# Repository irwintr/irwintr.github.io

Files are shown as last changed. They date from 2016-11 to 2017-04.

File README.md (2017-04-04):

---
csl: apa.csl
bibliography: RPiCitations.bib
---

**ActiveHouse**
===============

Project website <https://irwintr.github.io>

Prepared by Trenton Irwin

March 28, 2017

  \pagebreak   \linespread{2} \selectfont

**Declaration of Sole Authorship**
----------------------------------

I, Trenton Irwin, will be completing all of the work related to this project
including the hardware, database, web service, and mobile application. Any uses
made within it of the works of any other author, in any form (ideas, equations,
figures, texts, tables, programs), are properly acknowledged at the point of
use. A list of the references used is included. It is mandatory that all sources
of information be acknowledged in the SRS. Plagiarism is unethical and a
candidate suspected of plagiarizing may be referred to the Complaints Committee.

  \pagebreak

**Proposal**
------------

### **Proposal Table of Contents**

1.  [Proposal](https://github.com/irwintr/irwintr.github.io/blob/master/README.md#proposal)

2.  [Executive
    Summary](https://github.com/irwintr/irwintr.github.io/blob/master/README.md#executive-summary)

3.  [Background](https://github.com/irwintr/irwintr.github.io/blob/master/README.md#background)

4.  [Methodology](https://github.com/irwintr/irwintr.github.io/blob/master/README.md#methodology)

5.  [Concluding
    Remarks](https://github.com/irwintr/irwintr.github.io/blob/master/README.md#concluding-remarks)

6.  [References](https://github.com/irwintr/irwintr.github.io/blob/master/README.md#references)

The ActiveHouse Project would be a complete home monitoring system consisting of
multiple Arduino based sensor hubs in each room of your home wirelessly
connecting to a Raspberry Pi based base station which sends the data to the
server where it can be read by the app. Each sensor hub would be capable of
reading temperature, humidity, luminosity, carbon monoxide and other gas levels,
water consumption, power consumption, and it would have the ability to toggle
the built-in light. The power and water consumption sensors are detachable as
they would not necessarily be used in each room, thus creating a more modular
design. The app would allow users to view the current settings in each room and
over the complete house, toggle the lighting, and set a lighting schedule.

\#\#\# **Executive Summary**
----------------------------

As a Computer Engineering student, I’ll be using all of the skills I have
learned in the last 2 years in this program to complete this project. This
proposal requests the approval to build the hardware portion that will connect
to a database as well as to a mobile device application. The sensor hub hardware
will include a custom PCB with sensors and XBee wireless adapters and an Arduino
inside a custom printed box. The Base station hardware will include an XBee
wireless adapter connected to a Raspberry Pi. The database will store the sensor
data from each room. The mobile device functionality will allow users to view
the current settings in each room and over the complete house, toggle the
lighting, and set a lighting schedule. I may end up collaborating with the
greater Active House team later in the semester but I will not be working with
any companies. The hardware will be completed in CENG 317 Hardware Production
Techniques independently and the application will be completed in CENG 319
Software Project. These will be integrated together in the subsequent term in
CENG 355 Computer Systems Project.

\#\#\# **Background**
---------------------

The problem solved by this project is that it provides a home monitoring
solution so that users homes can be controlled and monitored remotely through an
intuitive app. It will help people monitor their resource consumption as well
which may help drive down consumption.

There are several other home monitoring solutions on the market now[@4429263],
but they are usually integrated into either the thermostat or home security
system. This is one of the first projects I’ve seen where water and power
consumption are also monitored on a residential scale.

In the Computer Engineering Technology program I have learned about the
following topics from the respective relevant courses:

-   Electronic Devices and Circuits – Soldering experience

-   Database with Java – Setting up database

-   Electronic Circuits – Voltage Divider calculations

-   Technical Workplace Writing – Creating write-ups and technical drawings

-   Software Engineering – Creating project schedules

This knowledge and skill set will enable me to build the subsystems and
integrate them together as my capstone project.

\#\#\# **Methodology**
----------------------

This proposal is assigned in the first week of class and is due at the beginning
of class in the second week of the fall semester. My coursework will focus on
the first two of the 3 phases of this project:  
Phase 1 Hardware build.  
Phase 2 System integration.  
Phase 3 Demonstration to future employers.

~~~~~~~~~~~~~~~~~~~~~~~~~~~~~~~~~~~~~~~~~~~~~~~~~~~~~~~~~~~~~~~~~~~~~~~~~~~~~~~~
*Phase 1 Hardware build*
~~~~~~~~~~~~~~~~~~~~~~~~~~~~~~~~~~~~~~~~~~~~~~~~~~~~~~~~~~~~~~~~~~~~~~~~~~~~~~~~

The hardware build will be completed in the fall term. It will fit within the
CENG Project maximum dimensions of 12 13/16" x 6" x 2 7/8" (32.5cm x 15.25cm x
7.25cm) which represents the space below the tray in the parts kit. The highest
AC voltage that will be used is 16Vrms from a wall adaptor from which +/- 15V or
as high as 45 VDC can be obtained. Maximum power consumption will be 20 Watts.

~~~~~~~~~~~~~~~~~~~~~~~~~~~~~~~~~~~~~~~~~~~~~~~~~~~~~~~~~~~~~~~~~~~~~~~~~~~~~~~~
*Phase 2 System integration*
~~~~~~~~~~~~~~~~~~~~~~~~~~~~~~~~~~~~~~~~~~~~~~~~~~~~~~~~~~~~~~~~~~~~~~~~~~~~~~~~

The system integration will be completed in the winter term.

*Phase 3 Demonstration to future employers*

This project will showcase the knowledge and skills that we have learned to
potential employers.

The tables below provide rough effort and non-labour estimates respectively for
each phase. A Gantt chart will be added by week 3 to provide more project
schedule details and a more complete budget will be added by week 4. It is
important to start tasks as soon as possible to be able to meet deadlines.

| **Labour Estimates** | **Hrs** | **Notes** |
|---|---|---|
| **Phase 1** | | |
| Writing proposal. | 9 | Tech identification quiz. |
| Creating project schedule. Initial project team meeting. | 9 | Proposal due. |
| Creating budget. Status Meeting. | 9 | Project Schedule due. |
| Acquiring components and writing progress report. | 9 | Budget due. |
| Mechanical assembly and writing progress report. Status Meeting. | 9 | Progress Report due (components acquired milestone). |
| PCB fabrication. | 9 | Progress Report due (Mechanical Assembly milestone). |
| Interface wiring, Placard design, Status Meeting. | 9 | PCB Due (power up milestone). |
| Preparing for demonstration. | 9 | Placard due. |
| Writing progress report and demonstrating project. | 9 | Progress Report due (Demonstrations at Open House Saturday, November 7, 2015 from 10 a.m. - 2 p.m.). |
| Editing build video. | 9 | Peer grading of demonstrations due. |
| Incorporation of feedback from demonstration and writing progress report. Status Meeting. | 9 | 30 second build video due. |
| Practice presentations | 9 | Progress Report due. |
| 1st round of Presentations, Collaborators present. | 9 | Presentation PowerPoint file due. |
| 2nd round of Presentations | 9 | Build instructions up due. |
| Project videos, Status Meeting. | 9 | 30 second script due. |
| **Phase 1 Total** | **135** | |
| **Phase 2** | | |
| Meet with collaborators | 9 | Status Meeting |
| Initial integration. | 9 | Progress Report |
| Meet with collaborators | 9 | Status Meeting |
| Testing. | 9 | Progress Report |
| Meet with collaborators | 9 | Status Meeting |
| Meet with collaborators | 9 | Status Meeting |
| Incorporation of feedback. | 9 | Progress Report |
| Meet with collaborators | 9 | Status Meeting |
| Testing. | 9 | Progress Report |
| Meet with collaborators | 9 | Status Meeting |
| Prepare for demonstration. | 9 | Progress Report |
| Complete presentation. | 9 | Demonstration at Open House Saturday, April 9, 2016 10 a.m. to 2 p.m. |
| Complete final report. 1st round of Presentations. | 9 | Presentation PowerPoint file due. |
| Write video script. 2nd round of Presentations, delivery of project. | 9 | Final written report including final budget and record of expenditures, covering both this semester and the previous semester. |
| Project videos. | 9 | Video script due |
| **Phase 2 Total** | **135** | |
| **Phase 3** | | |
| Interviews | TBD | |
| **Phase 3 Total** | **TBD** | |
| **Material Estimates** | **Cost** | **Supplier** |
| **Phase 1** | | |
| Cannakit Raspberry Pi v3 | \$99.99 | Amazon.ca |
| Arduino Uno SMD Rev3 | \$31.08 | Digi-key |
| Xbee S1 Trace Antenna (x2) | \$53.68 | Digi-key |
| Xbee Shield for Arduino | \$22.77 | Digi-key |
| 3.5mm audio jack | \$2.09 | Canada Robotix |
| Non-Invasive Current Sensor | \$13.19 | Canada Robotix |
| Adafruit Gas Sensor | \$21.12 | Digi-key |
| Adafruit Light Sensor | \$8.40 | Digi-key |
| Water Flow Sensor | \$11.89 | Canada Robotix |
| 3 Pin Molex header | \$0.39 | Canada Robotix |
| 12mm Buzzer | \$1.99 | Canada Robotix |
| Adafruit Temperature and Humidity Sensor | \$19.70 | Digi-key |
| *Shipping* | *\$6.95* | |
| *Tax* | *\$37.22* | |
| **Phase 1 Total** | **\$330.46** | |
| **Phase 2** | | |
| Materials to improve functionality, fit, and finish of project. | N/A | |
| **Phase 2 Total** | **TBD** | |
| **Phase 3** | | |
| **Phase 3 Total** | **TBD** | |

\#\#\# **Concluding remarks**
-----------------------------

This proposal presents a plan for providing an IoT solution for a home
monitoring system. This is an opportunity to integrate the knowledge and skills
developed in the Computer Engineering program to create a collaborative IoT
capstone project demonstrating my ability to learn how to support projects. I
request approval of this project.

  \pagebreak

**Abstract**
------------

This report contains information outlining the ActiveHouse home monitoring
system project. The project aims to create a complete home enviromental
monitoring system to measure temperature, humidity, light levels, water
consumption, power consumption, smoke and gas detection, and the ability to
toggle lights. There is an Android mobile application for displaying the data
and making changes. The hardware consists of a Raspberry Pi, an Arduino, xBee
wireless adapters, and a mirriad of sensors. The web service and database to
store all the data is hosted on Munro.humber.ca. The total cost for the
prototype is about \$330. The project will take me about 8 months to complete
but can be redone in much less time.  

  \pagebreak

**Table of Contents**
---------------------

1.  [Declaration of Sole
    Authorship](https://github.com/irwintr/irwintr.github.io/blob/master/README.md#declaration-of-sole-authorship)

2.  [Proposal](https://github.com/irwintr/irwintr.github.io/blob/master/README.md#proposal)

3.  [Abstract](https://github.com/irwintr/irwintr.github.io/blob/master/README.md#abstract)

4.  [Table of
    Contents](https://github.com/irwintr/irwintr.github.io/blob/master/README.md#table-of-contents)

5.  [List of Illustrations or
    Diagrams](https://github.com/irwintr/irwintr.github.io/blob/master/README.md#list-of-illustrations-or-diagrams)

6.  [Introduction](https://github.com/irwintr/irwintr.github.io/blob/master/README.md#introduction)

7.  [Project
    Description](https://github.com/irwintr/irwintr.github.io/blob/master/README.md#project-description)

8.  [Conclusion](https://github.com/irwintr/irwintr.github.io/blob/master/README.md#conclusion)

9.  [Appendicies](https://github.com/irwintr/irwintr.github.io/blob/master/README.md#appendicies)

10. [Bibliography](https://github.com/irwintr/irwintr.github.io/blob/master/README.md#bibliography)

  \pagebreak

**List of Illustrations or Diagrams**
-------------------------------------

1.  Project Workflow diagram

2.  Budget / Parts list

3.  XBee breakout board

4.  XBee to Pi wiring diagram

5.  Sensor Hub

6.  Sensor Hub

7.  Sensor Hub

8.  Sensor Hub

9.  Raspberry Pi base station

10. Sensor Hub

11. Sensor Hub

12. Sample output from sensor hub

13. Sensor hub with sensors attached

\pagebreak

**Introduction**
----------------

The ActiveHouse Project is a complete home monitoring system consisting of
multiple Arduino based sensor hubs in each room of your home wirelessly
connecting to a Raspberry Pi based base station which sends the data to the
server where it can be read by the app. Each sensor hub is be capable of reading
temperature, humidity, luminosity, carbon monoxide and other gas levels, water
consumption, power consumption, and it would have the ability to toggle the
built-in light. The power and water consumption sensors are detachable as they
would not necessarily be used in each room, thus creating a more modular design.
The app allows users to view the current settings in each room and over the
complete house, toggle the lighting, and set a lighting schedule.

  \pagebreak

**Project Description**
-----------------------

The ActiveHouse project consists of two main pieces of hardware:

Raspberry Pi based base station with an Xbee wireless antenna connected to it.

Arduino based sensor hub which includes the following:

–Xbee Wireless Antenna

–Light Sensor

–Gas Sensor

–Current Sensor

–Water Flow Sensor

–Temperature Sensor

–Humidity Sensor

–Remote Controllable Light

–Buzzer

You can have as may sensor hubs as you want hooked up to one base station, they
jut need to be within the 300 foot range for the XBees.

There are 5 main software components at work in the Active House system; the
Arduino code running on the Sensor Hubs, the C++ code running on the Raspberry
Pi base station, the PHP Web Service Running on Munro, the MySQL database on
Munro, and the mobile Android app.

### **Sensor Hub Code**

**Arduino Specifications**

The Arduino program communicates with the Base station over the XBee serial
communication to send sensor data and toggle the light status.

**Code Breakdown**

The program is written to initialize all of the sensors. After that, it waits
and listens on the XBee serial port for communication from the base station.
When it receives a message from the base station that includes that sensor hub’s
unique ID, it replies with all of the sensor data.

### **Base Station Code**

**Raspberry Pi Specifications**

The Raspberry Pi based Base Station is used to communicate with the Sensor Hubs
over the XBee serial communication to gather all of the sensor data and send it
to the web service running on Munro.

\*\* Code Breakdown\*\*

The code that is running on the Raspberry Pi is written in C++ using the
ArduPi.cpp library which makes it easier to communicate using the Xbee. The
service has a list of the registered sensor hubs, and goes in order,
broadcasting each RoomID over the Xbee. When the corresponding sensor hub
receives this message, it will reply with all of its sensor data. The Base
Station code then parses that response and sends it back to the web service that
is running on Munro.

### Database Specifications

**Database Type**

For the ActiveHouse project I am using a MySQL database hosted on Munro. It can
be administered through phpMyAdmin.

**Database Tables**

There are four tables that are used in the Firebase.

1.  USERS

2.  HOUSE

3.  ROOM

4.  ROOM\_DATA

**USERS** is the table in which all users who sign up for the ActiveHouse
application are stored. They are given a key as a unique identifier.

**HOUSE** is the table in which the names of houses and their data are stored.
Each house is unique via an HOUSEID identification key within the table.

**ROOM** is the table in which the rooms in each house are stored. It contains
the HOUSEID that it corresponds with, a unique ROOMID and the room name.

**ROOM\_DATA** is the table where the sensor readings for each room are stored.
It is identified by the unique ROOMID.

**Work Breakdown**

There is no further work that needs to be done to the database.

### **Mobile Application Specifications**

**Graphical User Interface Specifications**

**MainActivity:** The login screen of the application is the first presented
upon launching the application. The user may enter already existing credentials
into EditText fields and login, or may choose to go to the sign up activity,
both navigations via Buttons. There is a checkbox to save the entered username
to local storage to be auto populated in future sessions.

**RegisterActivity:** The sign up screen of the application can be accessed from
the login screen. It has EditText fields for gathering new user information
including their HOUSEID. Without a HOUSEID, they cannot create a new account.
Incorrect EditText entries will be communicated via Toast message asking for
re-entry.

**HomeActivity:** This is the main screen of the app where the user can view the
current settings of the user’s house. There is a hamburger menu with links to
the other pages including one for each room in the home. Users can logout from
the menu bar.

**RoomActivity:** This page has the sensor data from an individual room
displayed. The user can interact with the page by toggling the light or light
schedule or setting the time on or off for the light. There is a hamburger menu
with links to the other pages including one for each room in the home. Users can
logout from the menu bar.

**RoomViewActivity:** The room view activity is a listview with all of the rooms
in it. Users can select the room they wish to view and be taken to the
RoomActivity page for that room.

**Application Work Breakdown**

There are a few small bugs that I need to patch, but the app is working and
pretty much complete.

### **Web Specifications**

**Web Service Specifications**

The web service is written in php and hosted on Munro. It can be accessed at
munro.humber.ca/\~n01046059/ActiveHouse.

**Web Work Breakdown**

The side of the web service that interacts with the mobile app is complete and
does not require any changes. I do need to write the side of the web service
that connects to the Raspberry Pi to send and receive sensor data. Additionally
I need to write a program to run on the Raspberry Pi to send the data to the
server.

\pagebreak

### **Build Instructions**

My Active House project is a complete home monitoring system. The idea is that
you would have one Sensor Hub in each room of your home to collect data You
would have one Raspberry Pi based base station which all of the sensor hubs send
their data wirelessly to. The base station then sends the received sensor data
to the database for use in my app.



#### Parts:

Here is a list of all the parts and aproximate costs for one Raspberry Pi base
station and one Sensor Hub:

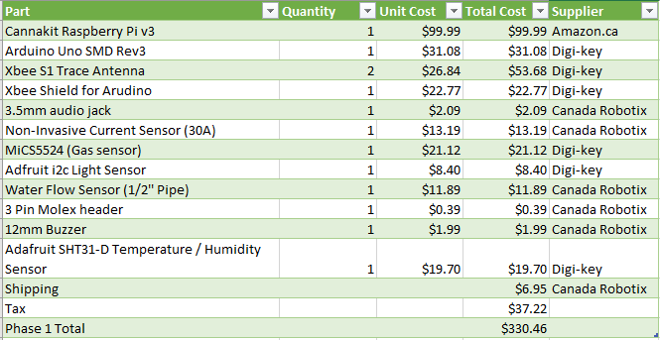
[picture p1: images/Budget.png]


This list does not include parts from the Humber electronics parts kit. The
parts you will need from the kit are:

-   220ohm Resistor

-   33ohm Resistor

-   2x 10Kohm Resistors

-   LED

-   50uf Capacitor

-   Single Core Wire

You will also need to print out the Acrylic case which can be found
[here](https://github.com/irwintr/irwintr.github.io/tree/master/Case) and the 2
PCBs which can be found
[here](https://github.com/irwintr/irwintr.github.io/tree/master/ArdunioShield)
and
[here](https://github.com/irwintr/irwintr.github.io/tree/master/XBeeBreakout).

#### Time Commitment

While it took me probably upwards of 30 hours to design the project and the
circuit boards, put it all together, and code it, I'd expect it to only take
around 5 hours to build the project again.

#### PCB/Soldering



The first board you will need to solder is the XBee Breakout board. You only
need to solder the 3.3v, GND, RX and TX pins as seen in this diagram:

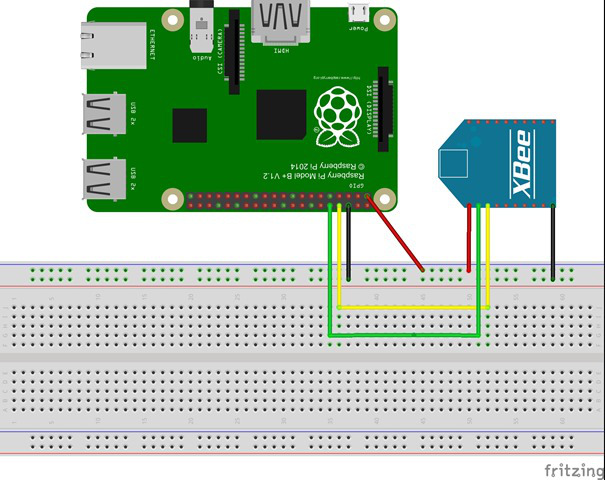
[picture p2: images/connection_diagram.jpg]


Then you will need to solder the Arduino Shield which includes all of the
sensors and connections. You can view the board and schematic files for this
board
[here](https://github.com/irwintr/irwintr.github.io/tree/master/ArdunioShield)
which will explain where all of the components and connections go. Beware, some
of the solder pads on the Arduin Shield are very small and you will need a very
steady hand to solder them. Below are a collection of images which will help you
understand where everything goes and how it is connected:









#### Mechanical Assembly



First, you will need to unbox your Raspberry Pi and set it up. You can view my
unboxing video [here](#Section_2). After that, connect the wires from the Xbee
breakout board to the appropriate GPIO pins.



Next you will need to build your acrylic case for your Arduino. Glue the all but
the back side together and glue the ports for the current and liquid sensors
onto the rear panel of the case.



#### Code

You can view the Arduino Code
[here](https://github.com/irwintr/irwintr.github.io/tree/master/ArduinoCode) to
read all of the sensor data and output it to Serial. You will also need to
include the Libraries folder. Due to a limitation with the Arduino Uno and the
Arduino XBee Shield, you cannot upload code to the Arduino while the XBee shield
is plugged in, so it needs to be removed from the arduino board when uploading.
Alternativly, you could flash the Arduino Uno's bootloader with the Duemilanove
which supports uploading code over XBee and send the code to the Arduino
wirelessly from the Raspberry Pi. You can read about how to flash the bootloader
[here](https://learn.sparkfun.com/tutorials/installing-an-arduino-bootloader)

#### Power Up

The output from the Arduino is below. You can also view my power up in my Build
Video.

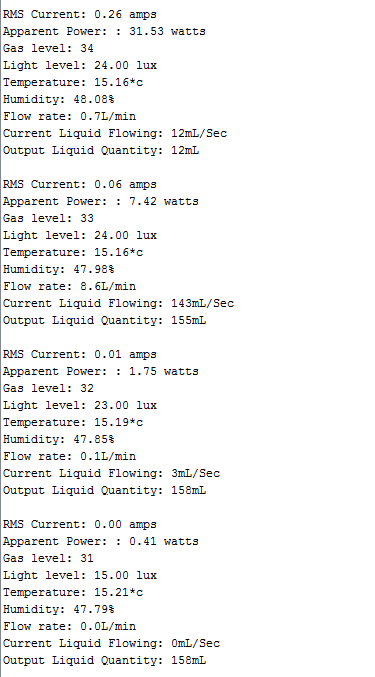
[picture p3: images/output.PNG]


#### Testing

In all of the testing I have done so far, everything works as expected. I've
checked the read values from the temperature, humidity, light, and gas sensors
and they all seem to be accurate. I have noth been able to find a 1/2" hose to
connect to my liquid flow sensor so I've been unable to calibrate it, but
tripping it by blowing air trough it works as expected. I've tested the current
sensor with a few different appliances and its's read values seem to be close to
the expected range, howeer I still need to completely calibrate it with an
clampmeter. The buzzer and LED can both be toggled from within the code.



\pagebreak

**Conclusions**
---------------

 The ActiveHouse project is nearly complete and will be within the next week. It
was definately a learning experience, but I fell like it was a sucessful
project. There are a few things I might do differently next time including
adding a Sync button to both the base station and the sensor boxes to pair them
automatically, however my current method of pairing works just fine. All of the
components of the project are working flawlessly together as expected, there is
just a bit of coding left to be done. The ActiveHouse project has great
potential as a home monitoring system as it has many features included such as
water and power consumption monitoring that aren't included in commercial
solutions that are currently on the market. Unfortunately, the fact that it's
build using mainly consumer hardware such as the Raspberry Pi and the Arduino
makes it not financially viable to birng to market without compltetely
rebuilding it all using cheaper microcontrollers. It was still a very good
learning experience and the skills that I have learned on this project will keep
me tinkering with electronics for years to come.  

\pagebreak

**Appendicies**
---------------

  \pagebreak

**Bibliography**
----------------

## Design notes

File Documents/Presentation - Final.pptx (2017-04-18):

## Active House

Trenton Irwin

## Introduction

- My Active House project is a complete home monitoring system.
- The idea is that you would have one Sensor Hub in each room of your home to collect data.
- You would have one Raspberry Pi based base station which all of the sensor hubs send their data wirelessly to via the Xbee wireless modules I have installed in all devices.
- The base station then sends the received sensor data to the web service which adds to to the database for use in my app.

- Raspberry Pi based base station with an Xbee wireless antenna connected to it.
- Arduino based sensor hub which includes the following:
  - Xbee Wireless Antenna
  - Light Sensor
  - Gas Sensor
  - Current Sensor
  - Water Flow Sensor
  - Temperature Sensor
  - Humidity Sensor
  - Remote Controllable Light
  - Buzzer

## Budget

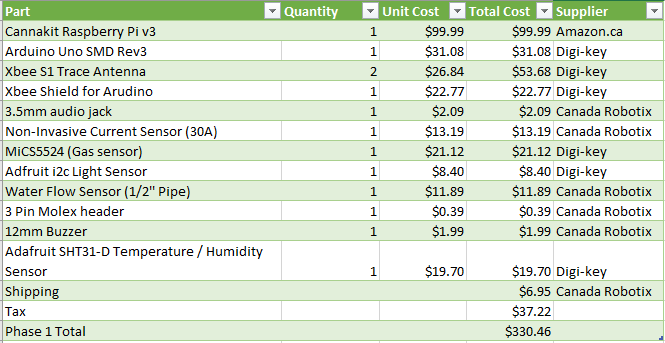
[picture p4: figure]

## Project Schedule

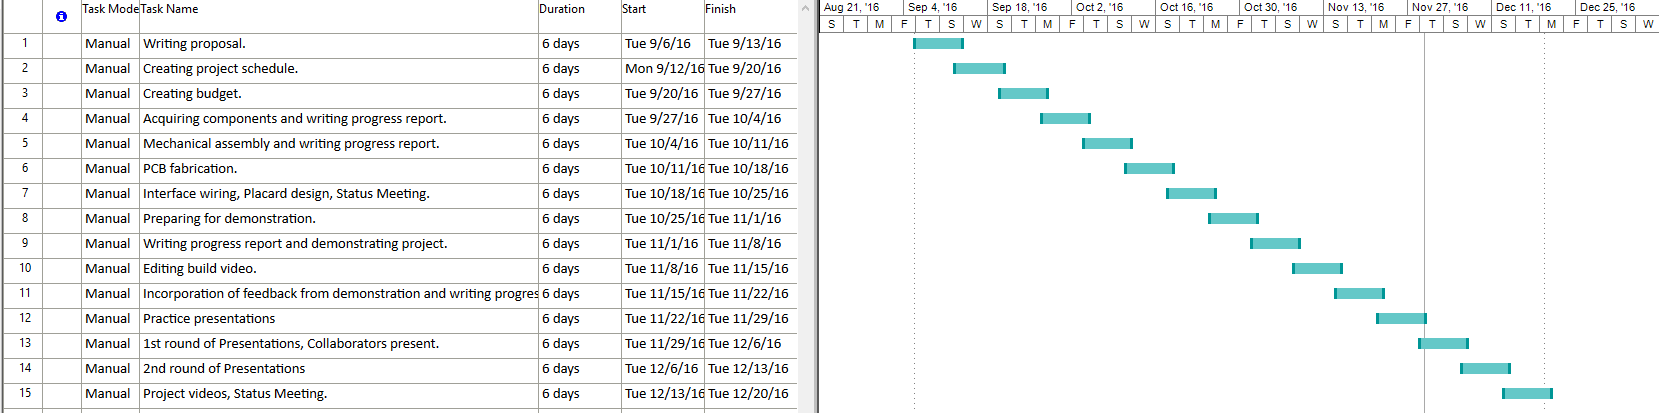
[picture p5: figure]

## Knowledge Used From Other Classes

- Electronic Devices and Circuits – Soldering experience
- Database with Java – Setting up database
- Electronic Circuits – Voltage Divider calculations
- Technical Workplace Writing – Creating write-ups and technical drawings
- Software Engineering – Creating project schedules
- Internet Programming – Writing web service

## Hardware

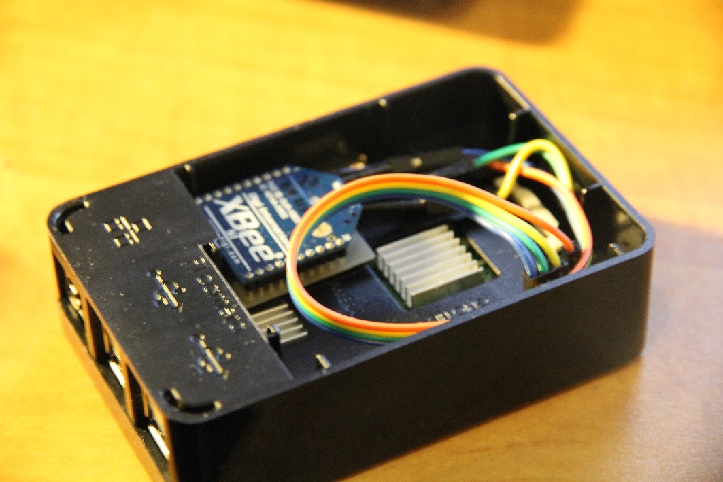
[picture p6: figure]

- Base Station
- Raspberry Pi 3 with Xbee Wireless module

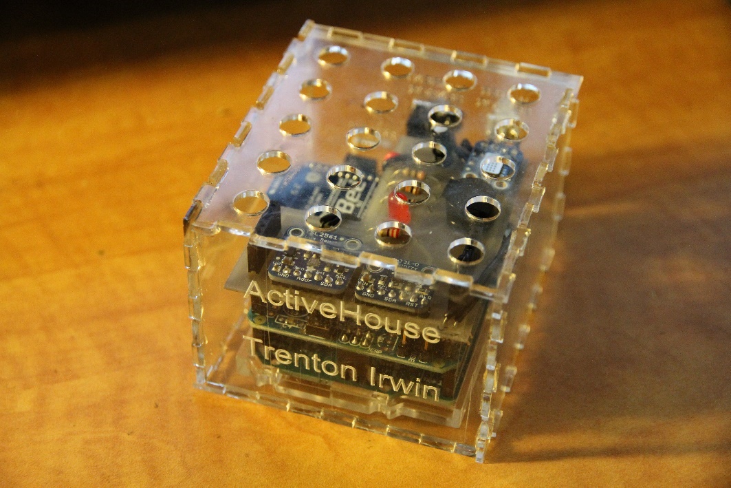
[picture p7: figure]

- Sensor Hub
- Arduino Uno with Xbee Wireless Antenna, Light Sensor, Gas Sensor, Current Sensor, Water Flow Sensor, Temperature Sensor, Humidity Sensor, Remote Controllable Light, and Buzzer

## Mobile Android Application

- The ActiveHouse Android app is used to view all of the sensor data from the

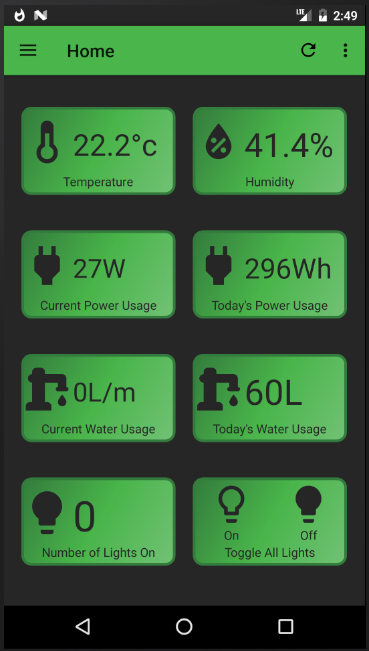
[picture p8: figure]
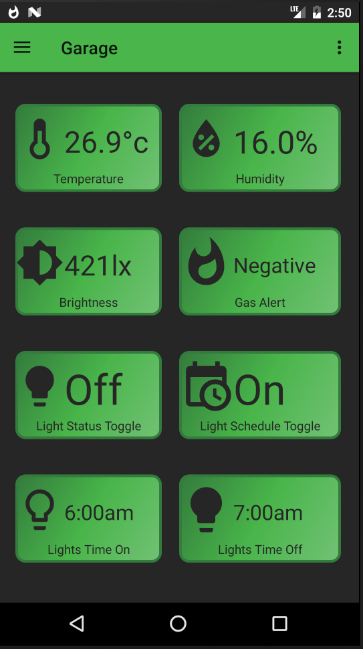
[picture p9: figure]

## Web Interface / Database

- I am using a MySQL database hosted on Munro to store all of my sensor data
- The web service is written in PHP and is used to communicate with both the mobile app and the Raspberry Pi base stations to send and receive data from the database.

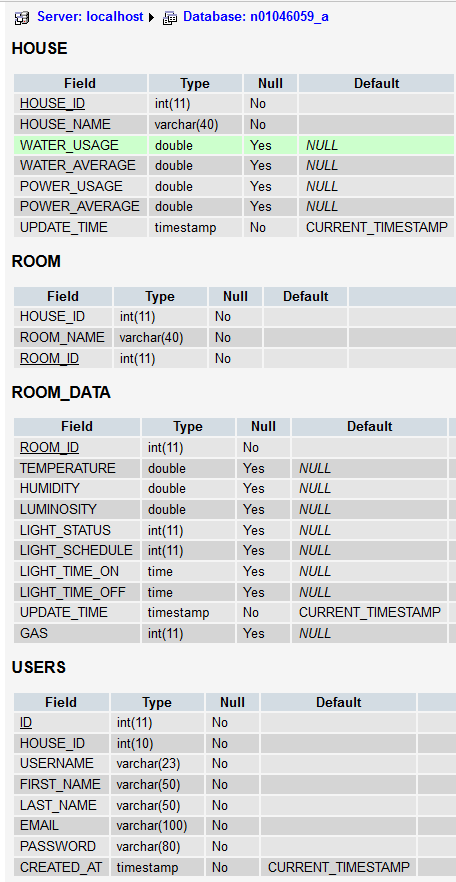
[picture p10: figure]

## Conclusion

- I consider my project to be a success because it is fully functional according to the original plan.
- It does represent a hole in the market for home monitoring devices, most of which don’t usually include all of the sensors I did for water and electricity monitoring.

- Unfortunately, to take the ActiveHouse project to market I would need to significantly reduce the build costs and move if off of Raspberry Pi and Arduino to cheaper micro controllers which would probably require a complete rewrite of the system.

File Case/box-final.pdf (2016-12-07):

POWER USB

SENSOR

CURRENT

WATER

SENSOR

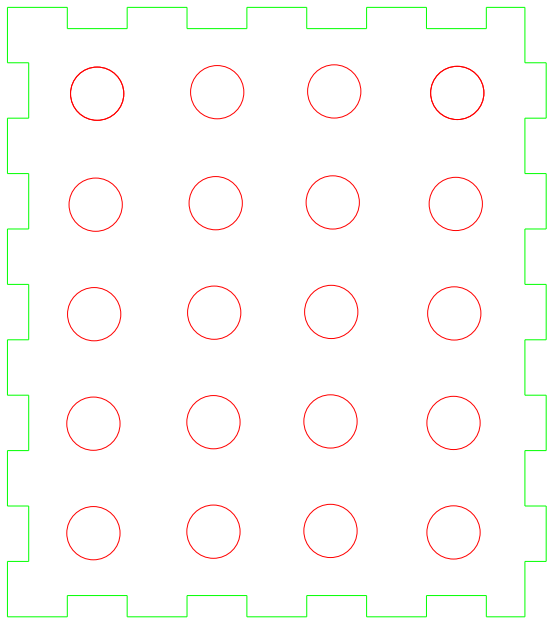
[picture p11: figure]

T
ActiveHouse
renton Irwin

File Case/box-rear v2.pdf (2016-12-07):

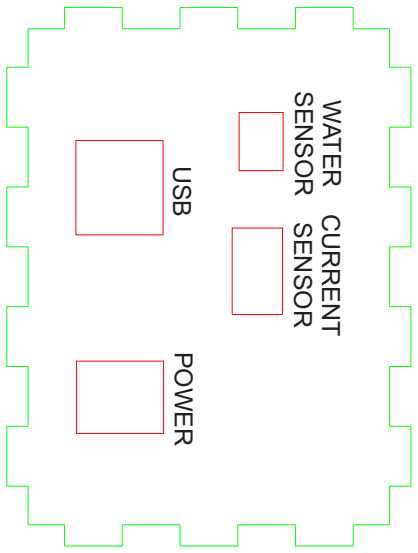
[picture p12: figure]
POWER USB; SENSOR; CURRENT WATER

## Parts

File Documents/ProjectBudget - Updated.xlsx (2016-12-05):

Part | Quantity | Unit Cost | Total Cost | Supplier | Trenton Irwin
Cannakit Raspberry Pi v3 | 1 | $99.99 | $99.99 | Amazon.ca | Oliver Duarte
Arduino Uno SMD Rev3 | 1 | $31.08 | $31.08 | Digi-key | Vishwas Malhotra
Xbee S1 Trace Antenna | 2 | $26.84 | $53.68 | Digi-key
Xbee Shield for Arudino | 1 | $22.77 | $22.77 | Digi-key
3.5mm audio jack | 1 | $2.09 | $2.09 | Canada Robotix
Non-Invasive Current Sensor (30A) | 1 | $13.19 | $13.19 | Canada Robotix
MiCS5524 (Gas sensor) | 1 | $21.12 | $21.12 | Digi-key
Adfruit i2c Light Sensor | 1 | $8.40 | $8.40 | Digi-key
Water Flow Sensor (1/2'' Pipe) | 1 | $11.89 | $11.89 | Canada Robotix
3 Pin Molex header | 1 | $0.39 | $0.39 | Canada Robotix
12mm Buzzer | 1 | $1.99 | $1.99 | Canada Robotix
Adafruit SHT31-D Temperature / Humidity Sensor | 1 | $19.70 | $19.70 | Digi-key
Shipping |  |  | $6.95 | Canada Robotix
Tax |  |  | $37.22
Phase 1 Total |  |  | $330.46

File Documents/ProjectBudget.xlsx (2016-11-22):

Material Estimates | Quantity | Unit Cost | Total Cost | Supplier | Group Members:
Phase 1 |  |  |  |  | Trenton Irwin
A microcomputer composed of a quad-core Windows 10 IoT core compatible Broadcom BCM2836 SoC with a 900MHz Application ARM Cortex-A7 32 bit RISC v7-A processor core stacked under 1GB of 450MHz SDRAM, 10/100 Mbit/s Ethernet, GPIO, UART, I²C bus, SPI bus, 8 GB of Secure Digital storage, a power supply, and a USB Wi-Fi adaptor. | 1 | $100 | $100 | Amazon.ca | Vishwas Malhotra
Arduino Nano | 3 | $20 | $60 | Amazon.ca | Oliver Duarte
Arduino compatible WiFi chip | 3 | $10 | $30 | Amazon.ca
5V DC Power supply | 3 | $5 | $15 | Amazon.ca
Light Sensor | 1 | $7 | $7 | Adafruit
Temperature / Humidity Sensor | 1 | $5 | $5 | Adafruit
Tax |  |  | $28.21
Phase 1 Total |  |  | $245.21
Phase 2
Arduino Nano | 8 | $20 | $160 | Amazon.ca
Arduino compatible WiFi chip | 8 | $10 | $80 | Amazon.ca
5V DC Power supply | 8 | $5 | $40 | Amazon.ca
Light Sensor | 8 | $7 | $56 | Adafruit
Temperature / Humidity Sensor | 8 | $5 | $40 | Adafruit
Tax |  |  | $48.88
Phase 2 Total |  |  | $424.88
Final Total |  |  | $670.09

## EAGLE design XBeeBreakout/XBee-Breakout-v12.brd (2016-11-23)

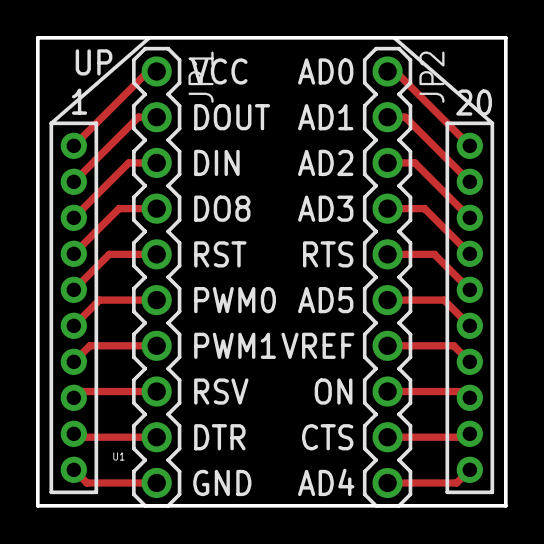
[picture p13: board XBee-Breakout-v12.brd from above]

Board: 2 copper layers, 26.0 x 26.0 mm, 4 parts (1 on the bottom side), 20 nets.

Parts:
JP1, JP2: 1X10
U1: XBEE; XBEE-1
U$2: LOGO-SFENEW; SFE-NEW-WEBLOGO

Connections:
unnamed: JP1.5, U1.5
unnamed: JP1.1, U1.1
unnamed: JP1.2, U1.2
unnamed: JP1.3, U1.3
unnamed: JP1.4, U1.4
unnamed: JP1.6, U1.6
unnamed: JP1.7, U1.7
unnamed: JP1.8, U1.8
unnamed: JP1.9, U1.9
unnamed: JP1.10, U1.10
unnamed: JP2.10, U1.11
unnamed: JP2.9, U1.12
unnamed: JP2.8, U1.13
unnamed: JP2.7, U1.14
unnamed: JP2.6, U1.15
unnamed: JP2.5, U1.16
unnamed: JP2.4, U1.17
unnamed: JP2.3, U1.18
unnamed: JP2.2, U1.19
unnamed: JP2.1, U1.20

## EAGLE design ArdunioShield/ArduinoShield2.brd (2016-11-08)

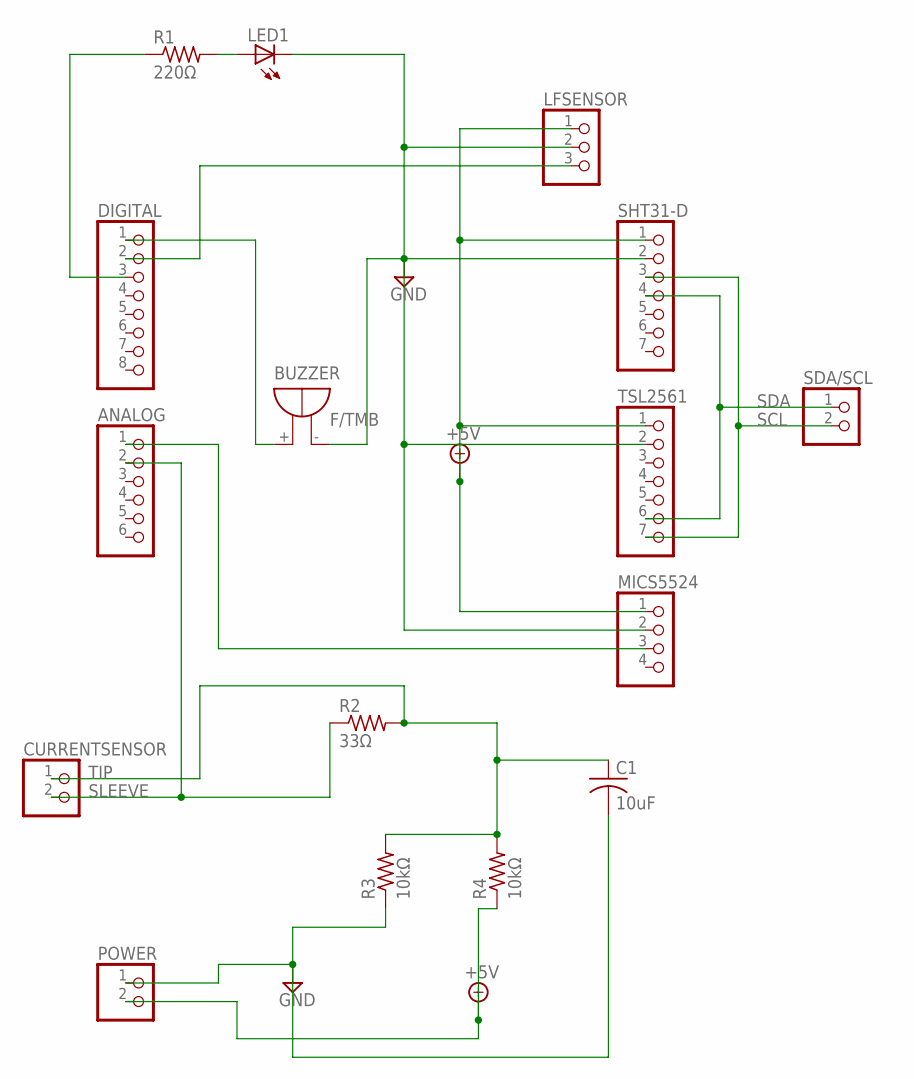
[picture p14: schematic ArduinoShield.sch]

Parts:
ANALOG: PINHD-1X6; 1X06
BUZZER: F/TMB
C1: 10uF; C025-060X050
CURRENTSENSOR: PINHD-1X2; 1X02
DIGITAL: PINHD-1X8; 1X08
LED1: LED5MM
LFSENSOR: PINHD-1X3; 1X03
MICS5524: PINHD-1X4; 1X04
POWER: PINHD-1X2; 1X02
R1: 220Ω; 0309/12
R2: 33Ω; 0309/12
R3, R4: 10kΩ; 0309/12
SDA/SCL: PINHD-1X2; 1X02
SHT31-D: PINHD-1X7; 1X07
TSL2561: PINHD-1X7; 1X07

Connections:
+5V: LFSENSOR.1, MICS5524.1, POWER.2, R4.1, SHT31-D.1, TSL2561.1
GND: BUZZER.-, C1.2, LED1.K (C), LFSENSOR.2, MICS5524.2, POWER.1, R3.1, SHT31-D.2, TSL2561.2
unnamed: ANALOG.1, MICS5524.3
unnamed: LED1.A, R1.2
unnamed: BUZZER.+, DIGITAL.1
unnamed: DIGITAL.2, LFSENSOR.3
unnamed: DIGITAL.3, R1.1
SCL: SDA/SCL.2, SHT31-D.3, TSL2561.7
SDA: SDA/SCL.1, SHT31-D.4, TSL2561.6
SLEEVE: ANALOG.2, CURRENTSENSOR.2, R2.1
TIP: C1.1, CURRENTSENSOR.1, R2.2, R3.2, R4.2

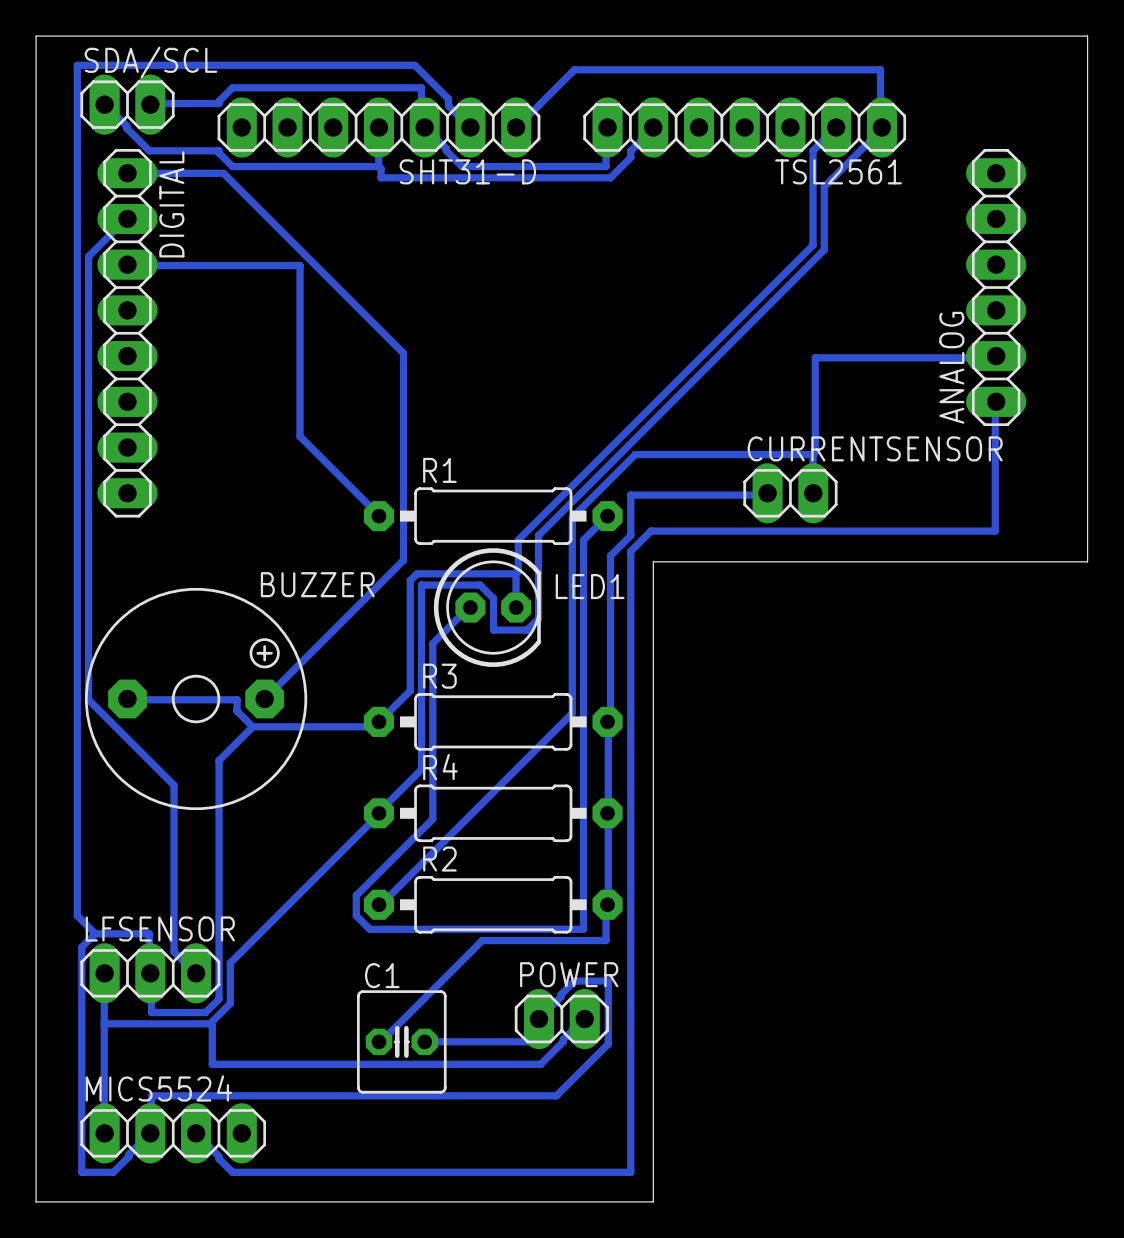
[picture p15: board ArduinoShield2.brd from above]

Board: 2 copper layers, 58.4 x 64.8 mm, 16 parts (0 on the bottom side), 11 nets.

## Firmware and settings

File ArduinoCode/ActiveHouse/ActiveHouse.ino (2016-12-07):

#include <Wire.h>
#include <Adafruit_Sensor.h>
#include <Adafruit_TSL2561_U.h>
#include <Arduino.h>
#include <Keyboard.h>
#include "EmonLib.h"                   // Include Emon Library
#include "Adafruit_SHT31.h"
   
Adafruit_TSL2561_Unified tsl = Adafruit_TSL2561_Unified(TSL2561_ADDR_FLOAT, 12345);
Adafruit_SHT31 sht31 = Adafruit_SHT31();

//Declare Curren Sensor
EnergyMonitor emon1;                   // Create an instance

byte statusLed    = 13;

byte sensorInterrupt = 1;  // 0 = digital pin 2
byte sensorPin       = 3;

// The hall-effect flow sensor outputs approximately 4.5 pulses per second per
// litre/minute of flow.
float calibrationFactor = 4.5;

volatile byte pulseCount;  

float flowRate;
unsigned int flowMilliLitres;
unsigned long totalMilliLitres;

unsigned long oldTime;



#if defined(ARDUINO_ARCH_SAMD)
// for Zero, output on USB Serial console, remove line below if using programming port to program the Zero!
   #define Serial SerialUSB
#endif

/*
Insterrupt Service Routine
 */
void pulseCounter()
{
  // Increment the pulse counter
  pulseCount++;
}



//Buzzer Code
void buzz(int targetPin, long frequency, long length) {
  long delayValue = 1000000/frequency/2; // calculate the delay value between transitions
  //// 1 second's worth of microseconds, divided by the frequency, then split in half since
  //// there are two phases to each cycle
  long numCycles = frequency * length/ 1000; // calculate the number of cycles for proper timing
  //// multiply frequency, which is really cycles per second, by the number of seconds to
  //// get the total number of cycles to produce
 for (long i=0; i < numCycles; i++){ // for the calculated length of time...
    digitalWrite(targetPin,HIGH); // write the buzzer pin high to push out the diaphram
    delayMicroseconds(delayValue); // wait for the calculated delay value
    digitalWrite(targetPin,LOW); // write the buzzer pin low to pull back the diaphram
    delayMicroseconds(delayValue); // wait againf or the calculated delay value
  }
}

/**************************************************************************/
/*
    Configures the gain and integration time for the TSL2561
*/
/**************************************************************************/
void configureSensor(void)
{
  /* You can also manually set the gain or enable auto-gain support */
  // tsl.setGain(TSL2561_GAIN_1X);      /* No gain ... use in bright light to avoid sensor saturation */
  // tsl.setGain(TSL2561_GAIN_16X);     /* 16x gain ... use in low light to boost sensitivity */
  tsl.enableAutoRange(true);            /* Auto-gain ... switches automatically between 1x and 16x */
  
  /* Changing the integration time gives you better sensor resolution (402ms = 16-bit data) */
  tsl.setIntegrationTime(TSL2561_INTEGRATIONTIME_13MS);      /* fast but low resolution */
  // tsl.setIntegrationTime(TSL2561_INTEGRATIONTIME_101MS);  /* medium resolution and speed   */
  // tsl.setIntegrationTime(TSL2561_INTEGRATIONTIME_402MS);  /* 16-bit data but slowest conversions */
}

/**************************************************************************/
/*
    Arduino setup function (automatically called at startup)
*/
/**************************************************************************/
void setup(void) 
{
  pinMode(4, OUTPUT); // set a pin for buzzer output
  
  #ifndef ESP8266
  while (!Serial);     // will pause Zero, Leonardo, etc until serial console opens
  #endif
  Serial.begin(9600);
  
  /* Initialise the sensor */
  if(!tsl.begin())
  {
    /* There was a problem detecting the TSL2561 ... check your connections */
    Serial.print("Ooops, no TSL2561 detected ... Check your wiring or I2C ADDR!");
    while(1);
  }

    emon1.current(1, 60);             // Current: input pin, calibration.

  
  /* Setup the sensor gain and integration time */
  configureSensor();

  if (! sht31.begin(0x44)) {   // Set to 0x45 for alternate i2c addr
    Serial.println("Couldn't find SHT31");
    while (1) delay(1);
  }

  // Set up the status LED line as an output
  pinMode(statusLed, OUTPUT);
  digitalWrite(statusLed, HIGH);  // We have an active-low LED attached
  
  pinMode(sensorPin, INPUT);
  digitalWrite(sensorPin, HIGH);

  pulseCount        = 0;
  flowRate          = 0.0;
  flowMilliLitres   = 0;
  totalMilliLitres  = 0;
  oldTime           = 0;

  // The Hall-effect sensor is connected to pin 2 which uses interrupt 0.
  // Configured to trigger on a FALLING state change (transition from HIGH
  // state to LOW state)
  attachInterrupt(sensorInterrupt, pulseCounter, FALLING);
  
  /* We're ready to go! */
  Serial.println("");
}

/**************************************************************************/
/*
    Arduino loop function, called once 'setup' is complete (your own code
    should go here)
*/
/**************************************************************************/
void loop(void) 
{ 
  //Temperature/ Humidity Sensor code
  float t = sht31.readTemperature();
  float h = sht31.readHumidity();

  //Current Sensor code
  double Irms = emon1.calcIrms(1480);  // Calculate Irms only
  Serial.print("RMS Current: "); Serial.print(Irms); Serial.println(" amps");         // Irms
  Serial.print("Apparent Power: : "); Serial.print(Irms*120.0); Serial.println(" watts");        // Apparent power
 
  //Gas sensor code
  int reading = analogRead(A0);
  Serial.print("Gas level: "); Serial.println(reading);
  if (reading > 100) {
    buzz(4, 2500, 500); // buzz the buzzer on pin 4 at 2500Hz for 1000 milliseconds
  }


  //Light Sensor code
  /* Get a new sensor event */ 
  sensors_event_t event;
  tsl.getEvent(&event);
  
  /* Display the results (light is measured in lux) */
  if (event.light)
  {
    Serial.print("Light level: "); Serial.print(event.light); Serial.println(" lux");
  }
  else
  {
    /* If event.light = 0 lux the sensor is probably saturated
       and no reliable data could be generated! */
    Serial.println("0.00 lux");
  }




  //Temperature/ Humidity Sensor code

  if (! isnan(t)) {  // check if 'is not a number'
    Serial.print
    ("Temperature: "); Serial.print(t); Serial.println("*c");
  } else { 
    Serial.println("Failed to read temperature");
  }
  
  if (! isnan(h)) {  // check if 'is not a number'
    Serial.print("Humidity: "); Serial.print(h); Serial.println("%");
  } else { 
    Serial.println("Failed to read humidity");
  }


  if((millis() - oldTime) > 1000)    // Only process counters once per second
  { 
    // Disable the interrupt while calculating flow rate and sending the value to
    // the host
    detachInterrupt(sensorInterrupt);
        
    // Because this loop may not complete in exactly 1 second intervals we calculate
    // the number of milliseconds that have passed since the last execution and use
    // that to scale the output. We also apply the calibrationFactor to scale the output
    // based on the number of pulses per second per units of measure (litres/minute in
    // this case) coming from the sensor.
    flowRate = ((1000.0 / (millis() - oldTime)) * pulseCount) / calibrationFactor;
    
    // Note the time this processing pass was executed. Note that because we've
    // disabled interrupts the millis() function won't actually be incrementing right
    // at this point, but it will still return the value it was set to just before
    // interrupts went away.
    oldTime = millis();
    
    // Divide the flow rate in litres/minute by 60 to determine how many litres have
    // passed through the sensor in this 1 second interval, then multiply by 1000 to
    // convert to millilitres.
    flowMilliLitres = (flowRate / 60) * 1000;
    
    // Add the millilitres passed in this second to the cumulative total
    totalMilliLitres += flowMilliLitres;
      
    unsigned int frac;
    
    // Print the flow rate for this second in litres / minute
    Serial.print("Flow rate: ");
    Serial.print(int(flowRate));  // Print the integer part of the variable
    Serial.print(".");             // Print the decimal point
    // Determine the fractional part. The 10 multiplier gives us 1 decimal place.
    frac = (flowRate - int(flowRate)) * 10;
    Serial.print(frac, DEC) ;      // Print the fractional part of the variable
    Serial.println("L/min");
    // Print the number of litres flowed in this second
    Serial.print("Current Liquid Flowing: ");             // Output separator
    Serial.print(flowMilliLitres);
    Serial.println("mL/Sec");

    // Print the cumulative total of litres flowed since starting
    Serial.print("Output Liquid Quantity: ");             // Output separator
    Serial.print(totalMilliLitres);
    Serial.println("mL"); 

    // Reset the pulse counter so we can start incrementing again
    pulseCount = 0;
    
    // Enable the interrupt again now that we've finished sending output
    attachInterrupt(sensorInterrupt, pulseCounter, FALLING);
  }
  Serial.println("");
  delay(1000);
}

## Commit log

2016-09-20 Raspberry Pi Lights
2016-11-08 Week 10 Progress Report
    [ArduinoShield.sch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]
2016-11-22 Update week 12
    [ProjectBudget.xlsx]
2016-11-23 Added Schematic and gerbers for xbee breakout
    [XBee-Breakout-v12.brd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]
2016-12-05 added updated budget
    [ProjectBudget - Updated.xlsx]
